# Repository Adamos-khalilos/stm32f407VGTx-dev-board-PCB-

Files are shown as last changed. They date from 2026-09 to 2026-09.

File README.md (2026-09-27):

# STM32F407VGTx Dev Board

A custom STM32F407VGTx development board featuring USB-C power/data, a microSD card slot, SWD debugging, a wake-up button, RGB status LEDs, and a clean regulated power supply. Designed entirely in KiCad.

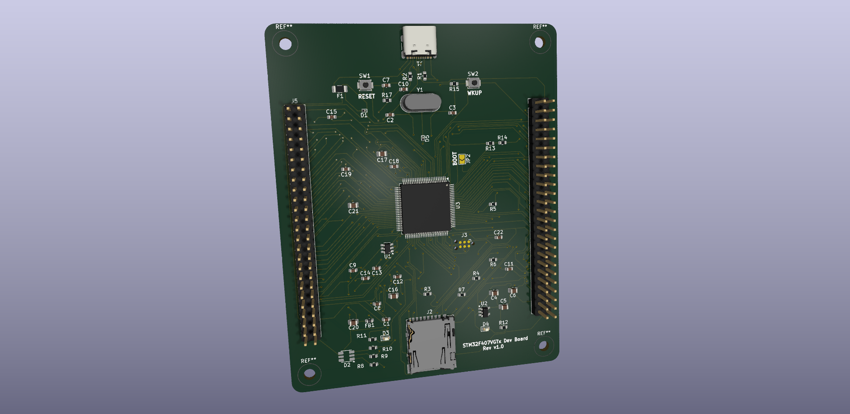
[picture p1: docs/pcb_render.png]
PCB Render

<!-- Replace with your 3D render or PCB photo -->

## Features

- **MCU**: STM32F407VGTx (ARM Cortex-M4, up to 168 MHz)
- **USB**: USB-C receptacle (USB 2.0) with ESD protection (USBLC6-2P6) and BOOT0 select button
- **Power**: 5V → 3.3V regulation via LP5907MFX-3.3 LDO, decoupled with a full capacitor array on VDD/VDDA
- **Storage**: microSD card socket with dedicated pull-ups on DAT0–3/CMD/CLK and card-detect pins
- **Debug**: SWD header (Tag-Connect TC2030-NL footprint) — SWDIO, SWCLK, nRST, VCC, GND
- **Reset circuit**: Dedicated reset button with debounce and PWR_FLAG supervision
- **Wake-up circuit**: Dedicated WKUP button on a pull-down
- **Clock**: 8 MHz external crystal (HSE) with 27pF load capacitors
- **Status LEDs**: RED, GREEN, BLUE, ORANGE user LEDs (330 Ω current-limiting resistors)
- **Expansion**: Two 2×25 GPIO headers (J4 "right side", J5 "left side") breaking out nearly all MCU pins, plus 3V3/5V/GND rails

## Power Architecture

| Stage | Description |
|---|---|
| USB-C VBUS (5V) | Main input power from USB-C connector (J1) |
| LP5907MFX-3.3 (U2) | Linear regulator, 5V → 3.3V |
| VDD / VDDA decoupling | Array of 100 nF capacitors + bulk 4.7 µF on the MCU supply rails |
| High-frequency filtering | Ferrite bead (FB1) + local 100 pF / 4.7 µF caps close to VREF/VDDA for clean ADC reference |

## USB-C Interface (J1)

- USB 2.0 receptacle, D+/D− routed to PA11/PA12
- ESD protection via USBLC6-2P6 (U1)
- BOOT0 select button (SW1) with pull resistors for entering system bootloader mode

## microSD Card Interface (J2)

| Signal | Description |
|---|---|
| DAT0–DAT3 | SDIO data lines (10 kΩ pull-ups) |
| CLK (SDIO_CLK) | SDIO clock |
| CMD (SDIO_CMD) | SDIO command line (10 kΩ pull-up) |
| SD_DETECT / DET_A / DET_B | Card presence detection |
| SHIELD (SH) | Connector shield, tied to GND |

## SWD Debug Header (J3 — Tag-Connect TC2030-NL)

| Signal | Description |
|---|---|
| VCC | +3V3 |
| SWDIO | Serial wire data |
| SWCLK | Serial wire clock |
| nRST | Reset |
| GND | Ground |

## Reset Circuit

Push-button reset with RC debounce, PWR_FLAG supervision, and a jumper (JP2) for optional external reset control.

## Wake-Up Circuit

Dedicated button (SW2) on the WKUP pin, pulled down through a 10 kΩ resistor.

## User LEDs

| LED | Color | Driver Resistor |
|-----|---|---|
| D2 | Red | R9 (330 Ω) |
| D3 | Green | R10 (330 Ω) |
| D4 | Blue | R8 (330 Ω) |
| D5 | Orange | R11 (330 Ω) |

## Clock

8 MHz crystal (Y1) on HSE, with 27 pF load capacitors (C2, C3).

## GPIO Expansion Headers (J4 / J5)

Two 2×25 (50-pin) headers break out the majority of the STM32F407's GPIO ports (PA, PB, PC, PD, PE), along with GND, +3V3 and +5V rails on both headers for powering external modules.

> For the exact pin-by-pin mapping, refer to `stm32.kicad_sch` (sheet "Connector Headers") or export a netlist/pin table from KiCad — this avoids transcription errors from a schematic screenshot.

## Repository Structure
.
├── stm32.kicad_pro # KiCad project file
├── stm32.kicad_sch # Schematic
├── stm32.kicad_pcb # PCB layout
├── fp-lib-table # Footprint library table
├── Library.pretty/ # Local custom footprints
└── README.md

## Getting Started

1. Clone this repository
2. Open `stm32.kicad_pro` in [KiCad](https://www.kicad.org/) (v7 or later recommended)
3. Review the schematic (`stm32.kicad_sch`) and PCB layout (`stm32.kicad_pcb`)
4. Run DRC (Design Rules Check) before ordering fabrication
5. Generate Gerbers / fabrication files when ready to manufacture

## License

This project is licensed under the MIT License — see [LICENSE](LICENSE) for details.

## Author

Designed by **Khalil Adem**

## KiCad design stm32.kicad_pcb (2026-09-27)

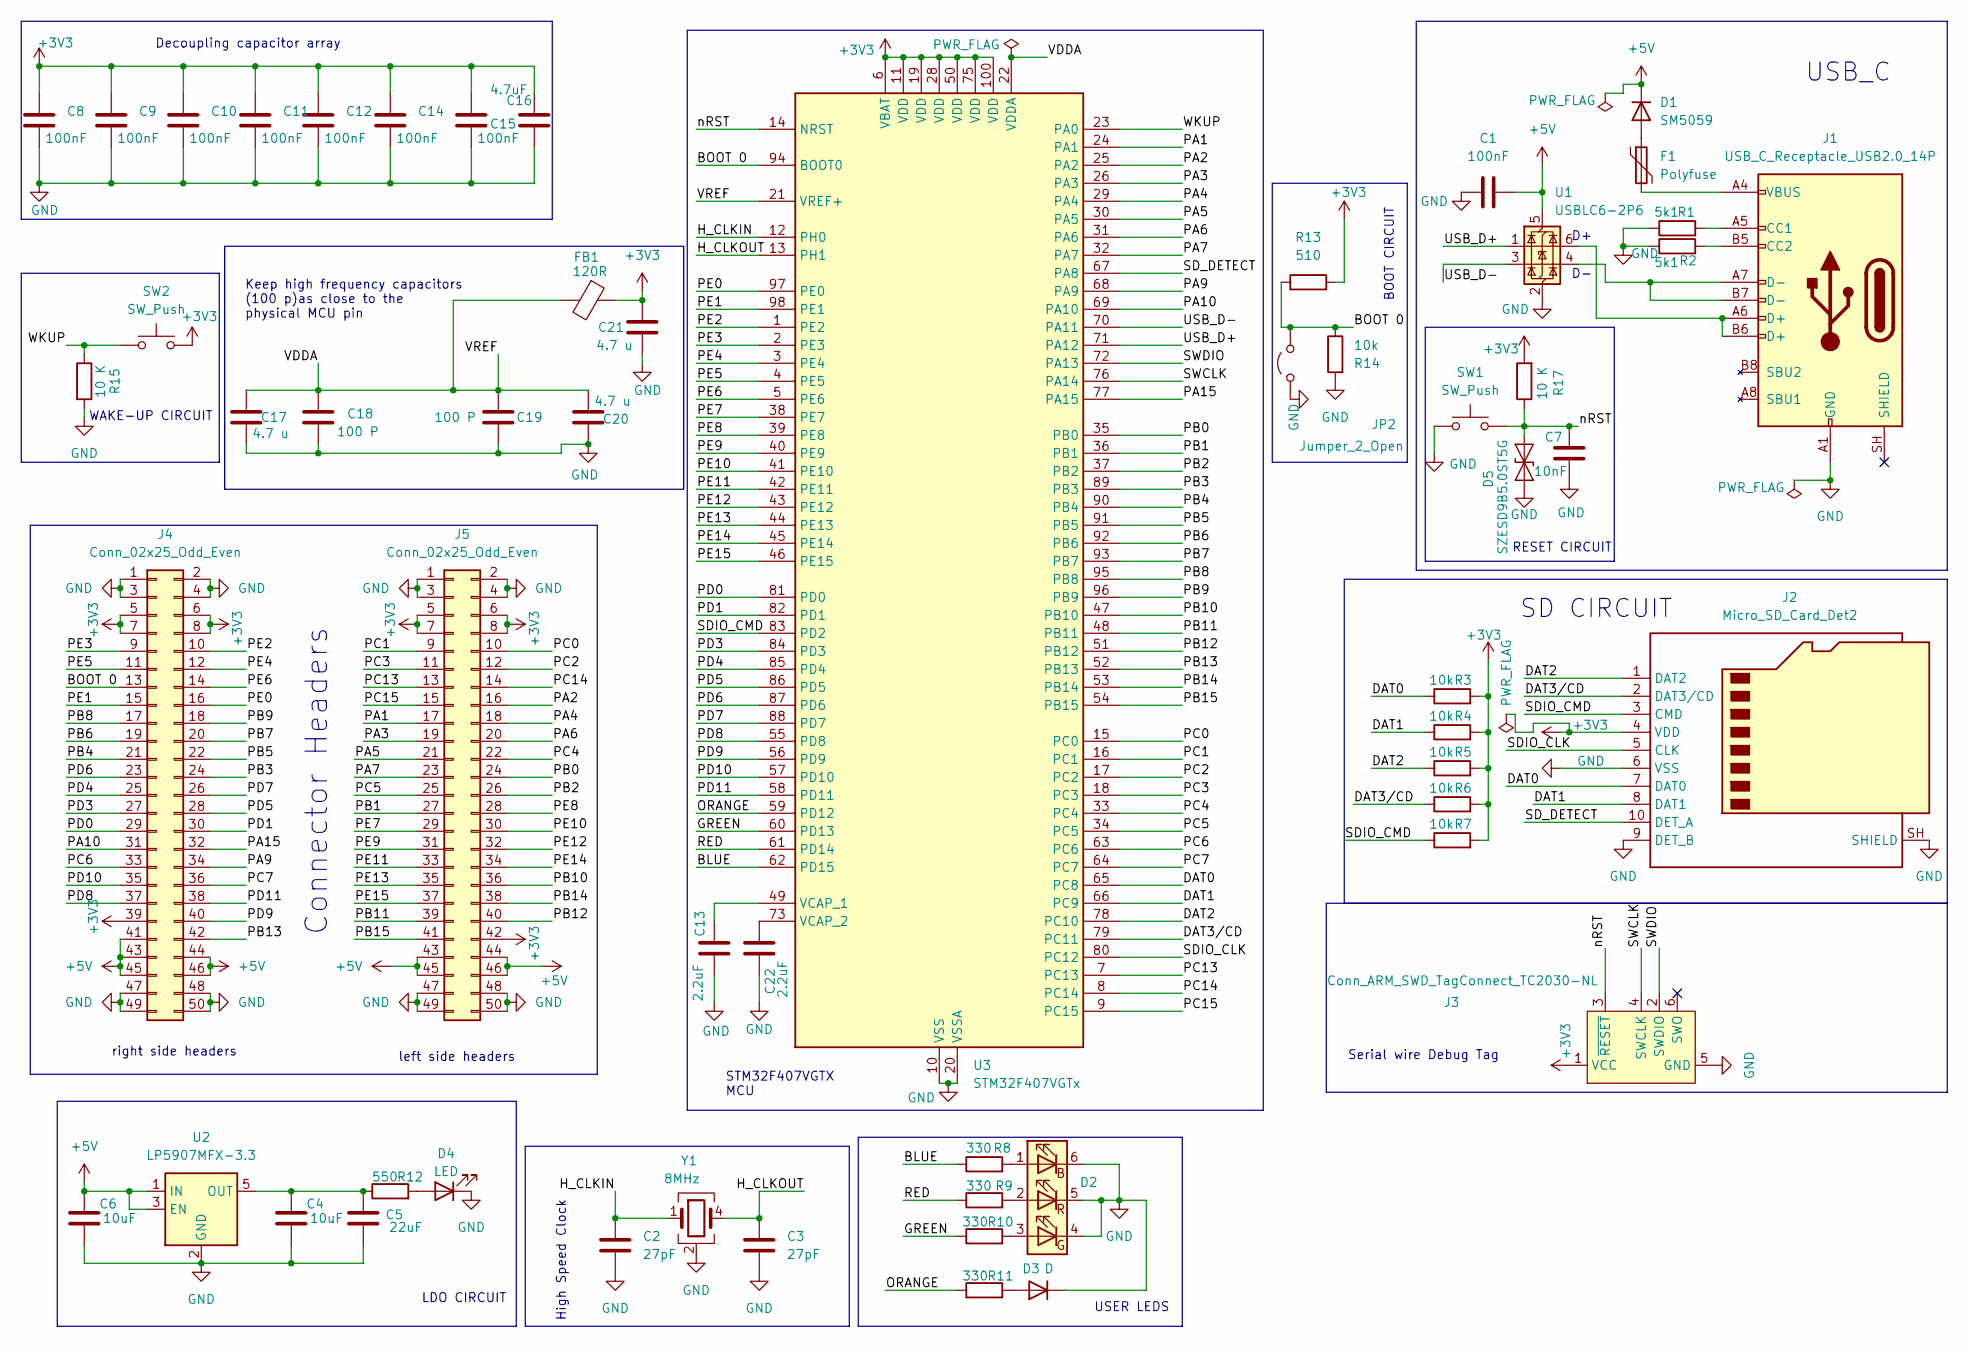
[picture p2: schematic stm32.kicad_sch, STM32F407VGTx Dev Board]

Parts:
C1, C8, C9, C10, C11, C12, C14, C15: 100nF; C_0603_1608Metric
C2, C3: 27pF; C_0603_1608Metric
C4, C6: 10uF; C_0805_2012Metric
C5: 22uF; C_0805_2012Metric
C7: 10nF; C_0603_1608Metric
C13, C22: 2.2uF; C_0603_1608Metric
C16: 4.7uF; C_0805_2012Metric
C17, C20, C21: 4.7 u; C_0805_2012Metric
C18, C19: 100 P; C_0603_1608Metric
D1: SM5059; D_SOD-923
D2: SMLVN6RGB; LED_ROHM_SMLVN6
D3: D; LED_0603_1608Metric
D4: LED; LED_0603_1608Metric
D5: SZESD9B5.0ST5G; D_SOD-923
F1: Polyfuse; Fuse_1206_3216Metric
FB1: 120R; L_0603_1608Metric
J1: USB_C_Receptacle_USB2.0_14P; USB_C_Receptacle_GCT_USB4105-xx-A_16P_TopMnt_Horizontal
J2: Micro_SD_Card_Det2; microSD_HC_Hirose_DM3AT-SF-PEJM5
J3: Conn_ARM_SWD_TagConnect_TC2030-NL; Tag-Connect_TC2030-IDC-NL_2x03_P1.27mm_Vertical
J4, J5: Conn_02x25_Odd_Even; PinHeader_2x25_P2.54mm_Vertical
JP2: Jumper_2_Open; SolderJumper-2_P1.3mm_Open_TrianglePad1.0x1.5mm
R1, R2: 5k1; R_0603_1608Metric
R3, R4, R5, R6, R7, R14: 10k; R_0603_1608Metric
R8, R9, R10, R11: 330; R_0603_1608Metric
R12: 550; R_0603_1608Metric
R13: 510; R_0603_1608Metric
R15, R17: 10 K; R_0603_1608Metric
SW1, SW2: SW_Push; SW_SPST_B3U-1000P
U1: USBLC6-2P6; SOT-23-6
U2: LP5907MFX-3.3; SOT-23-5
U3: STM32F407VGTx; LQFP-100_14x14mm_P0.5mm
Y1: 8MHz; Crystal_HC49-4H_Vertical

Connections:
+3V3: C8.1, C9.1, C10.1, C11.1, C12.1, C14.1, C15.1, C16.1, C21.1, FB1.1, J2.4 (VDD), J3.1 (VCC), J4.5, J4.6, J4.7, J4.8, J4.39, J5.5, J5.6, J5.7, J5.8, J5.42, R3.2, R4.2, R5.2, R6.2, R7.2, R13.2, R17.2, SW2.2, U3.6 (VBAT), U3.11 (VDD), U3.19 (VDD), U3.28 (VDD), U3.50 (VDD), U3.75 (VDD), U3.100 (VDD)
+5V: C1.2, C6.1, D1.1 (K), J4.41, J4.43, J4.44, J4.45, J4.46, J5.43, J5.44, J5.45, J5.46, U1.5 (VBUS), U2.1 (IN), U2.3 (EN)
/BLUE: R8.1, U3.62 (PD15)
/BOOT 0: J4.13, JP2.2 (B), R13.1, R14.1, U3.94 (BOOT0)
/DAT0: J2.7 (DAT0), R3.1, U3.65 (PC8)
/DAT1: J2.8 (DAT1), R4.1, U3.66 (PC9)
/DAT2: J2.1 (DAT2), R5.1, U3.78 (PC10)
/DAT3/CD: J2.2 (DAT3/CD), R6.1, U3.79 (PC11)
/GREEN: R10.1, U3.60 (PD13)
/H_CLKIN: C2.1, U3.12 (PH0), Y1.1
/H_CLKOUT: C3.1, U3.13 (PH1), Y1.4
/ORANGE: R11.1, U3.59 (PD12)
/PA1: J5.17, U3.24 (PA1)
/PA2: J5.16, U3.25 (PA2)
/PA3: J5.19, U3.26 (PA3)
/PA4: J5.18, U3.29 (PA4)
/PA5: J5.21, U3.30 (PA5)
/PA6: J5.20, U3.31 (PA6)
/PA7: J5.23, U3.32 (PA7)
/PA9: J4.34, U3.68 (PA9)
/PA10: J4.31, U3.69 (PA10)
/PA15: J4.32, U3.77 (PA15)
/PB0: J5.24, U3.35 (PB0)
/PB1: J5.27, U3.36 (PB1)
/PB2: J5.26, U3.37 (PB2)
/PB3: J4.24, U3.89 (PB3)
/PB4: J4.21, U3.90 (PB4)
/PB5: J4.22, U3.91 (PB5)
/PB6: J4.19, U3.92 (PB6)
/PB7: J4.20, U3.93 (PB7)
/PB8: J4.17, U3.95 (PB8)
/PB9: J4.18, U3.96 (PB9)
/PB10: J5.36, U3.47 (PB10)
/PB11: J5.39, U3.48 (PB11)
/PB12: J5.40, U3.51 (PB12)
/PB13: J4.42, U3.52 (PB13)
/PB14: J5.38, U3.53 (PB14)
/PB15: J5.41, U3.54 (PB15)
/PC0: J5.10, U3.15 (PC0)
/PC1: J5.9, U3.16 (PC1)
/PC2: J5.12, U3.17 (PC2)
/PC3: J5.11, U3.18 (PC3)
/PC4: J5.22, U3.33 (PC4)
/PC5: J5.25, U3.34 (PC5)
/PC6: J4.33, U3.63 (PC6)
/PC7: J4.36, U3.64 (PC7)
/PC13: J5.13, U3.7 (PC13)
/PC14: J5.14, U3.8 (PC14)
/PC15: J5.15, U3.9 (PC15)
/PD0: J4.29, U3.81 (PD0)
/PD1: J4.30, U3.82 (PD1)
/PD3: J4.27, U3.84 (PD3)
/PD4: J4.25, U3.85 (PD4)
/PD5: J4.28, U3.86 (PD5)
/PD6: J4.23, U3.87 (PD6)
/PD7: J4.26, U3.88 (PD7)
/PD8: J4.37, U3.55 (PD8)
/PD9: J4.40, U3.56 (PD9)
/PD10: J4.35, U3.57 (PD10)
/PD11: J4.38, U3.58 (PD11)
/PE0: J4.16, U3.97 (PE0)
/PE1: J4.15, U3.98 (PE1)
/PE2: J4.10, U3.1 (PE2)
/PE3: J4.9, U3.2 (PE3)
/PE4: J4.12, U3.3 (PE4)
/PE5: J4.11, U3.4 (PE5)
/PE6: J4.14, U3.5 (PE6)
/PE7: J5.29, U3.38 (PE7)
/PE8: J5.28, U3.39 (PE8)
/PE9: J5.31, U3.40 (PE9)
/PE10: J5.30, U3.41 (PE10)
/PE11: J5.33, U3.42 (PE11)
/PE12: J5.32, U3.43 (PE12)
/PE13: J5.35, U3.44 (PE13)
/PE14: J5.34, U3.45 (PE14)
/PE15: J5.37, U3.46 (PE15)
/RED: R9.1, U3.61 (PD14)
/SDIO_CLK: J2.5 (CLK), U3.80 (PC12)
/SDIO_CMD: J2.3 (CMD), R7.1, U3.83 (PD2)
/SD_DETECT: J2.10 (DET_A), U3.67 (PA8)
/SWCLK: J3.4 (SWCLK), U3.76 (PA14)
/SWDIO: J3.2 (SWDIO), U3.72 (PA13)
/USB_D+: U1.1 (I/O1), U3.71 (PA12)
/USB_D-: U1.3 (I/O2), U3.70 (PA11)
/VDDA: C17.1, C18.1, C19.1, C20.1, FB1.2, U3.21 (VREF+), U3.22 (VDDA)
/WKUP: R15.1, SW2.1, U3.23 (PA0)
/nRST: C7.1, D5.2 (A2), J3.3 (~RESET), R17.1, SW1.2, U3.14 (NRST)
GND: C1.1, C2.2, C3.2, C4.2, C5.2, C6.2, C7.2, C8.2, C9.2, C10.2, C11.2, C12.2, C13.2, C14.2, C15.2, C16.2, C17.2, C18.2, C19.2, C20.2, C21.2, C22.2, D2.4 (GK), D2.5 (RK), D2.6 (BK), D3.1 (K), D4.1 (K), D5.1 (A1), J1.A1 (GND), J1.A12 (GND), J1.B1 (GND), J1.B12 (GND), J2.6 (VSS), J2.9 (DET_B), J2.SH (SHIELD), J3.5 (GND), J4.1, J4.2, J4.3, J4.4, J4.47, J4.48, J4.49, J4.50, J5.1, J5.2, J5.3, J5.4, J5.47, J5.48, J5.49, J5.50, JP2.1 (A), R1.1, R2.1, R14.2, R15.2, SW1.1, U1.2 (GND), U2.2 (GND), U3.10 (VSS), U3.20 (VSSA), U3.27 (VSS), U3.74 (VSS), U3.99 (VSS), Y1.2 (G), Y1.3 (G)
unnamed: D1.2 (A), F1.1
unnamed: D2.1 (BA), R8.2
unnamed: D2.3 (GA), R10.2
unnamed: D2.2 (RA), R9.2
unnamed: D3.2 (A), R11.2
unnamed: D4.2 (A), R12.2
unnamed: F1.2, J1.A4 (VBUS), J1.A9 (VBUS), J1.B4 (VBUS), J1.B9 (VBUS)
unnamed: J1.A5 (CC1), R1.2
unnamed: J1.B5 (CC2), R2.2
unnamed: J1.A6 (D+), J1.B6 (D+), U1.6 (I/O1)
unnamed: J1.A7 (D-), J1.B7 (D-), U1.4 (I/O2)
unnamed: C4.1, C5.1, R12.1, U2.5 (OUT)
unnamed: C13.1, U3.49 (VCAP_1)
unnamed: C22.1, U3.73 (VCAP_2)

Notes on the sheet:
STM32F407VGTX MCU
WAKE-UP CIRCUIT
High Speed Clock
Keep high frequency capacitors (100 p)as close to the physical MCU pin
LDO CIRCUIT
SD CIRCUIT
USB_C
Decoupling capacitor array
left side headers
USER LEDS
RESET CIRCUIT
Connector Headers
right side headers
Serial wire Debug Tag
BOOT CIRCUIT

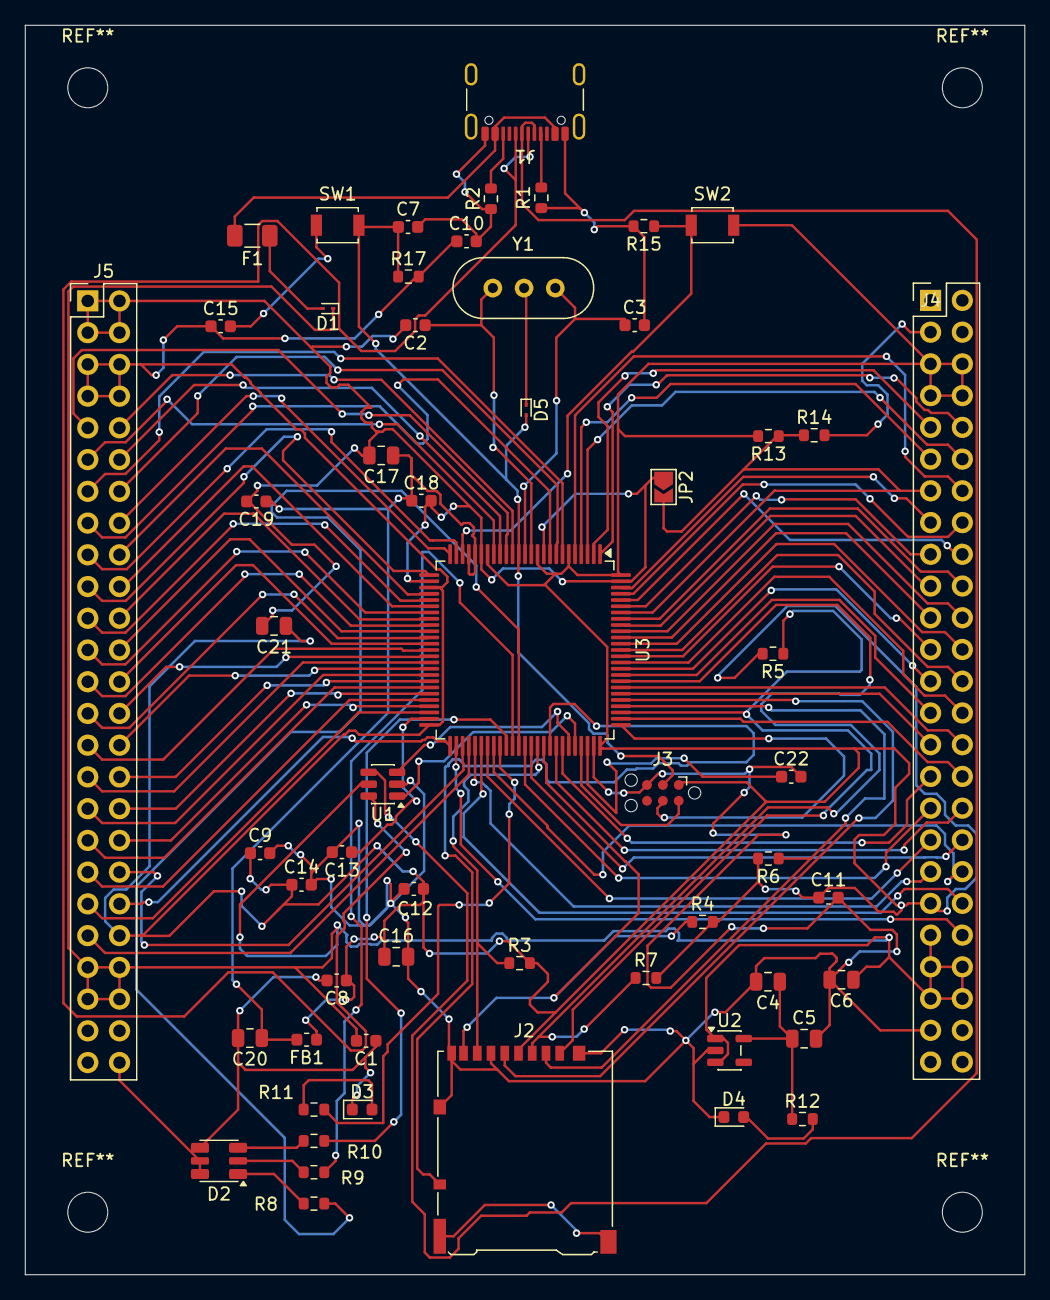
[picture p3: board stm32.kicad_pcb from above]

Board: 2 copper layers, 80.0 x 100.0 mm, 57 parts (0 on the bottom side), 102 nets.

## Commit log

2026-09-27 Add KiCad project files
    [stm32.kicad_pcb, stm32.kicad_sch]
2026-09-27 Revise README with enhanced board features and details
    Updated project description and features for clarity and detail.
2026-09-27 Add PCB render image
